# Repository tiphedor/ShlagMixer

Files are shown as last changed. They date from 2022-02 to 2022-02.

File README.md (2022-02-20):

# ShlagMixer - a DIY midi audio mixer

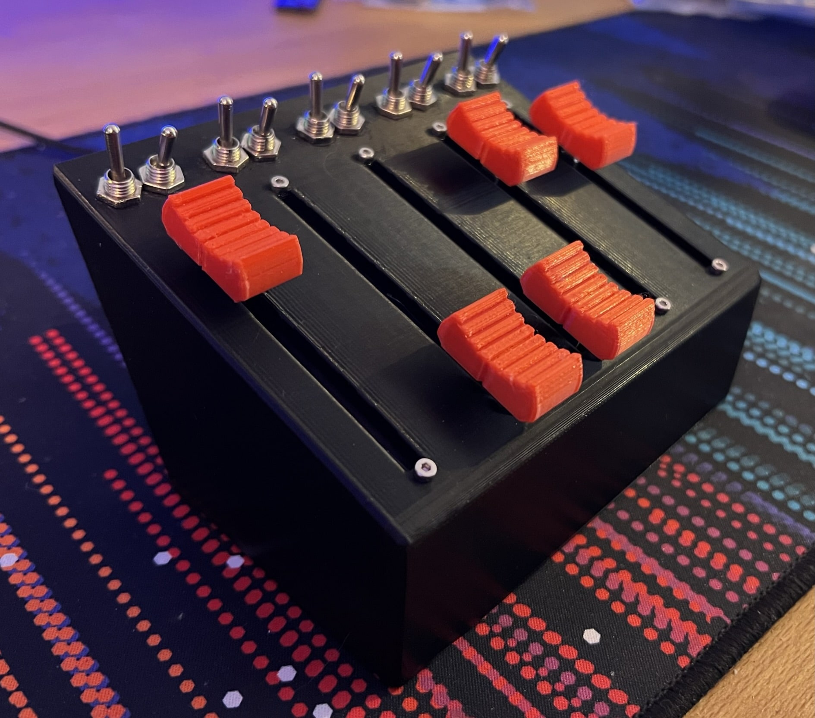
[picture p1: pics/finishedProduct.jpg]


## Table of Contents

  - [Hardware](#hardware)
    + [BOM](#bom)
    + [Electronics](#electronics)
  - [Software](#software)
    + [Arduino](#arduino)
    + [AutoHotKey](#autohotkey)
  - [3D printed parts](#3d-printed-parts)

--- 

The point of this project is to control [Voicemeeter Banana](https://vb-audio.com/Voicemeeter/banana.htm) - which is the audio mixer I use during my [Twitch streams](https://twitch.tv/tiphedor) - with a physical controller. This version can control the gain of 5 channels, as well as toggle said channels to 2 outputs. It can be adapted and scaled up/down to suit different needs fairly easily.

## Hardware

### BOM

 - 10x SPDT toggle switches or similar
 - 5x linear potentiometer / fader, 10k
 - Arduino Leonardo. Pro mini/micro will work too, use the one you like as long as it's Atmega32u4-based (must be HID capable to act as a MIDIUSB device)
 - Wires (lol)
 - 3d printer
 
### Electronics
 
Wiring is fairly easy, one side of each button goes to ground, middle sides (COM) to digital pins D4-D13. For the faders, you can use this (very shitty) image: 
 
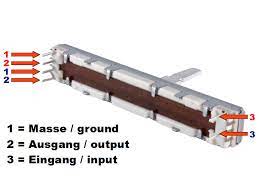
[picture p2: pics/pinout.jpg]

 
Connect red1 to ground, red2 to A0-A4, and red3 to +5V. You can leave blue1, blue2 and blue3 NC.
 
Here's a rough schematic, disclaimer I've drawn it after putting the project together, so it's probably not very accurate :D 
 
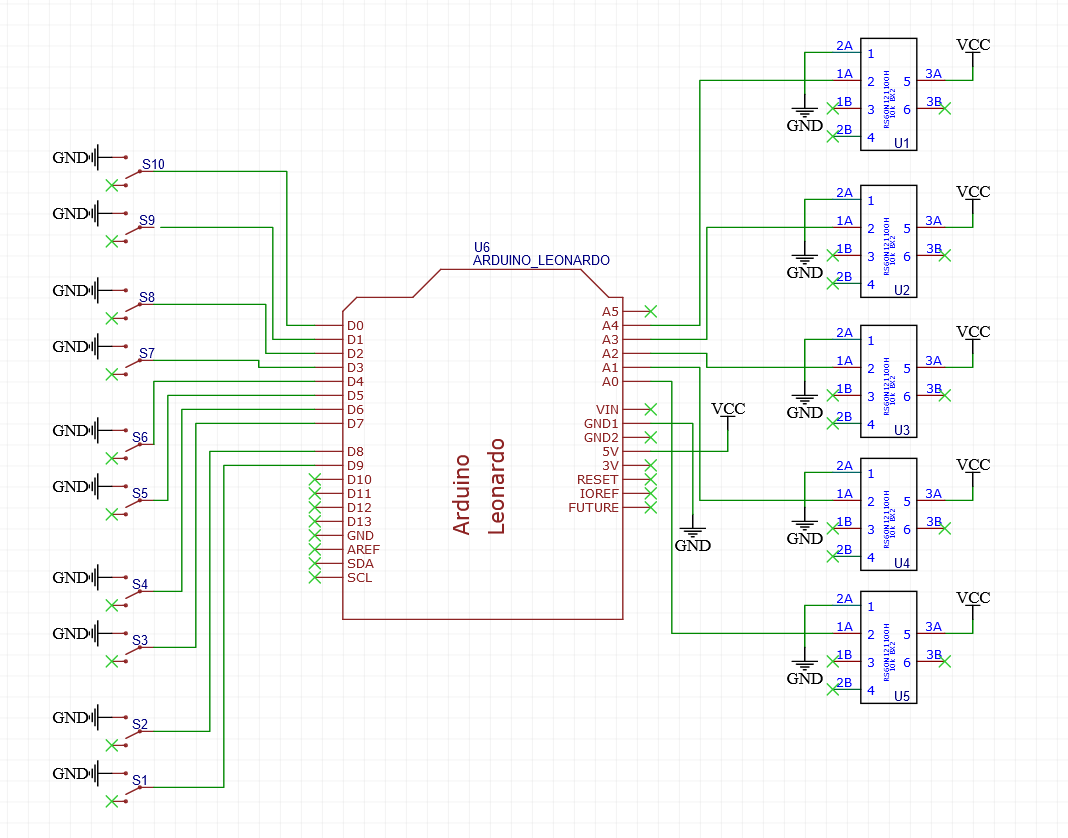
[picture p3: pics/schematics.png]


## Software

### Arduino

Open the project with [PlatformIO](https://platformio.org/), run : 

```bash
pio lib install
pio run
```

You should see a new device connected to your computer. I suggest using [MidiView](https://hautetechnique.com/midi/midiview/) to make sure the data is being received as you'd expect.

### AutoHotKey

Download and install [AutoHotKey](https://www.autohotkey.com/), then right-click the `main.ahk` file, click on "compile", which should produce a binary, `main.exe`. Run the binary - profit ! You can make the script run at startup by [following the official documentation](https://www.autohotkey.com/docs/FAQ.htm#Startup).

## 3D printed parts

You will need to print the mixer itself `shlagMixer.stl`, as well as 5 faders knobs `faderKnob.stl`. You can use whatever settings you'd like, neither are very hard to print. Mine were printed on a Prusa Mk3s, Prusament Black PLA, default profile, 0.2mm layer height. No supports required, and no raft either.

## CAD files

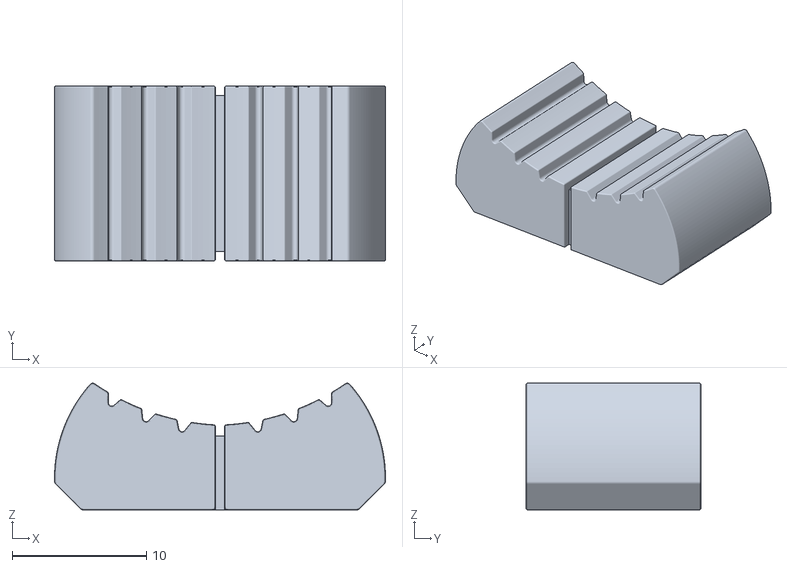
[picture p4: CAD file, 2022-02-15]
3d/faderKnob.stl
24.6 x 13.0 x 9.42

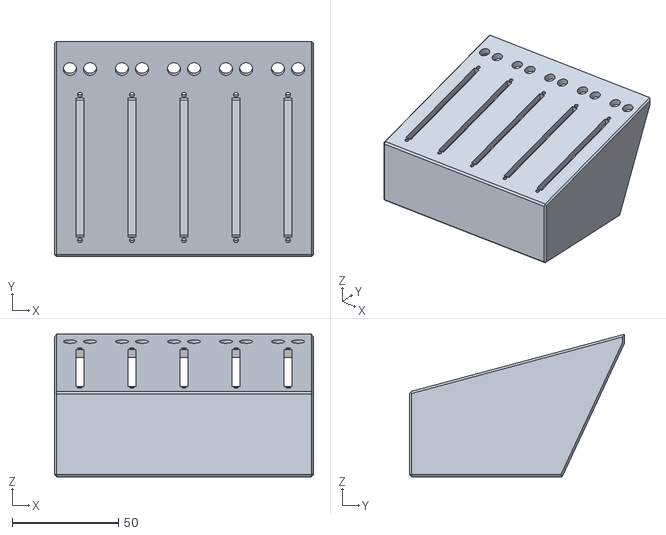
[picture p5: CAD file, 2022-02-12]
3d/shlagMixer.stl
122.0 x 101.4 x 67.2

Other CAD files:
3d/ShlagMixer.f3z

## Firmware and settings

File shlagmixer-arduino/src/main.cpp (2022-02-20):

#include "midi.hpp"

#define FADERS_COUNT 5
#define SWITCHES_COUNT 10
const int FADERS_PINS[] = { A0, A1, A2, A3, A4 };
const int SWITCHES_PINS[] = { 4, 5, 6, 7, 8, 9, 10, 11, 12, 13 };
#define DEBOUNCE_THR 2

int SWITCHES_STATES[SWITCHES_COUNT];
int FADERS_STATES[FADERS_COUNT];

void setup() {
  // Faders
  for (int i = 0; i < FADERS_COUNT; i++) {
    pinMode(FADERS_PINS[i], INPUT);
    FADERS_STATES[i] = analogRead(FADERS_PINS[i]);
  }


  // Switches
  for (int i = 0; i < SWITCHES_COUNT; i++) {
    pinMode(SWITCHES_PINS[i], INPUT_PULLUP);
    SWITCHES_STATES[i] = digitalRead(SWITCHES_PINS[i]);
  }
}

void loop() {
  // Faders
  // We send data on channel 32, 33, 34, 35, ... etc, this is arbitrary and can be changed as long as its also changed in the ahk file.
  for (int i = 0; i < FADERS_COUNT; i++) {
    int readState = analogRead(FADERS_PINS[i]);

    // If currentState - DEBOUNCE_THR < newState < currentStatet + DEBOUNCE_THR, threshold is used because the faders are quite noisy
    if (readState < FADERS_STATES[i] - DEBOUNCE_THR ||  readState > FADERS_STATES[i] + DEBOUNCE_THR) {
      FADERS_STATES[i] = readState; // update the current state

      // Send the note, we read a value withn 0-1023, MIDI uses 0-127, so remap the value
      controlChange(0, 32 + i, map(readState, 0, 1023, 0, 127));
    }
  }

  // Toggle switches
  // We send notes 12, 13, 14, ... etc, this is arbitrary and can be changed as long as its also changed in the ahk file.
  for (int i = 0; i < SWITCHES_COUNT; i++) {
    int readState = digitalRead(SWITCHES_PINS[i]);

    // Has button state changed ?
    if (readState != SWITCHES_STATES[i]) {      
      SWITCHES_STATES[i] = readState;

      if (readState == HIGH) {
        noteOn(0, 12 + i, 64);
      } else {
        noteOff(0, 12 + i, 64);
      }
    }
  }

  midiEventPacket_t rx;
  // Read incoming data - when we receive note 11 - send the current state.
  do {
    rx = MidiUSB.read();
    if (rx.header != 0) {
      byte command = rx.byte1;
      byte note = rx.byte2;

      // 144 = noteOn command - form the MIDI standard
      // 11 = arbitrary and can be changed as long as its also changed in the ahk file.
      // We don't care about velocity
      if (command == 144 && note == 11) {
        for (int i = 0; i < FADERS_COUNT; i++) {
          controlChange(0, 32 + i, map(FADERS_STATES[i], 0, 1023, 0, 127));
        }

        for (int i = 0; i < SWITCHES_COUNT; i++) {
          if (SWITCHES_STATES[i] == HIGH) {
            noteOn(0, 12 + i, 64);
          } else {
            noteOff(0, 12 + i, 64);
          }
        }
      }
    }
  } while (rx.header != 0);
  

  MidiUSB.flush();
  delay(25);
}

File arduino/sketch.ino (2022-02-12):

#include "MIDIUSB.h"

#define FADERS_COUNT 5
#define SWITCHES_COUNT 10

const int FADERS_PINS[] = { A0, A1, A2, A3, A4 };
const int SWITCHES_PINS[] = { 4, 5, 6, 7, 8, 9, 10, 11, 12, 13 };

int SWITCHES_STATES[SWITCHES_COUNT];
int FADERS_STATES[FADERS_COUNT];

void setup() {
  for (int i = 0; i < FADERS_COUNT; i++) {
    pinMode(FADERS_PINS[i], INPUT);
  }
  for (int i = 0; i < SWITCHES_COUNT; i++) {
    pinMode(SWITCHES_PINS[i], INPUT_PULLUP);

    int readValue = digitalRead(SWITCHES_PINS[i]);
    SWITCHES_STATES[i] = readValue;
    if (readValue == HIGH) {
      noteOn(0, 12 + i, 64);
    }
  }

  MidiUSB.flush();
}

void loop() {
  for (int i = 0; i < FADERS_COUNT; i++) {
    int readState = analogRead(FADERS_PINS[i]);
    if (
          readState < FADERS_STATES[i] - 1
      ||  readState > FADERS_STATES[i] + 1
    ) {
      FADERS_STATES[i] = readState;

      controlChange(0, 32 + i, map(readState, 0, 1023, 0, 127));
      MidiUSB.flush();
    }
  }

  for (int i = 0; i < SWITCHES_COUNT; i++) {
    int readState = digitalRead(SWITCHES_PINS[i]);
    if (readState != SWITCHES_STATES[i]) {      
      SWITCHES_STATES[i] = readState;
      if (readState == HIGH) {
        noteOn(0, 12 + i, 64);
      } else {
        noteOff(0, 12 + i, 64);
      }

      MidiUSB.flush();
    }
  }

  delay(25);
}



// MIDIUSB stuff
void noteOn(byte channel, byte pitch, byte velocity) {
  midiEventPacket_t noteOn = {0x09, 0x90 | channel, pitch, velocity};
  MidiUSB.sendMIDI(noteOn);
}

void noteOff(byte channel, byte pitch, byte velocity) {
  midiEventPacket_t noteOff = {0x08, 0x80 | channel, pitch, velocity};
  MidiUSB.sendMIDI(noteOff);
}

void controlChange(byte channel, byte control, byte value) {
  midiEventPacket_t event = {0x0B, 0xB0 | channel, control, value};
  MidiUSB.sendMIDI(event);
}

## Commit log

2022-02-15 added fader knob
    [faderKnob.stl]
2022-02-20 Make notes/strip map global (because button orientation - flemme de les changer)
